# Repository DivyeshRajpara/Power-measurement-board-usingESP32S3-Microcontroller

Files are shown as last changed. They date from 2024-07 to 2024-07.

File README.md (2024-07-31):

# Power-measurement-board-usingESP32S3-Microcontroller
This project involves the development of a power-measurement board designed using KiCad and programmed with the ESP32-S3 microcontroller. The board measures electrical power and transmits the data via BLE to a mobile device. The project includes KiCad design files, ESP32-S3 firmware, and a mobile app interface for real-time data monitoring.
components
Hardware: KiCad design files for the power measurement board.
Firmware: ESP32-S3 code for data acquisition and BLE communication.
Devices: Interface for displaying real-time power data on a mobile device.
features
Power Measurement: Accurate measurement of voltage, current, and power.
Bluetooth Low Energy: Wireless data transmission to mobile devices.
ESP32-S3 Microcontroller: High-performance MCU with integrated Wi-Fi and BLE.
KiCad Design: Open-source PCB design with comprehensive schematics and layout files.
3D Top View
3D Bottom View

FootPrint AKL073
FootPrint INA239
FootPrint RTM_Solder Nail
With Dimension
With Ground
Without Ground
Schematic INA239

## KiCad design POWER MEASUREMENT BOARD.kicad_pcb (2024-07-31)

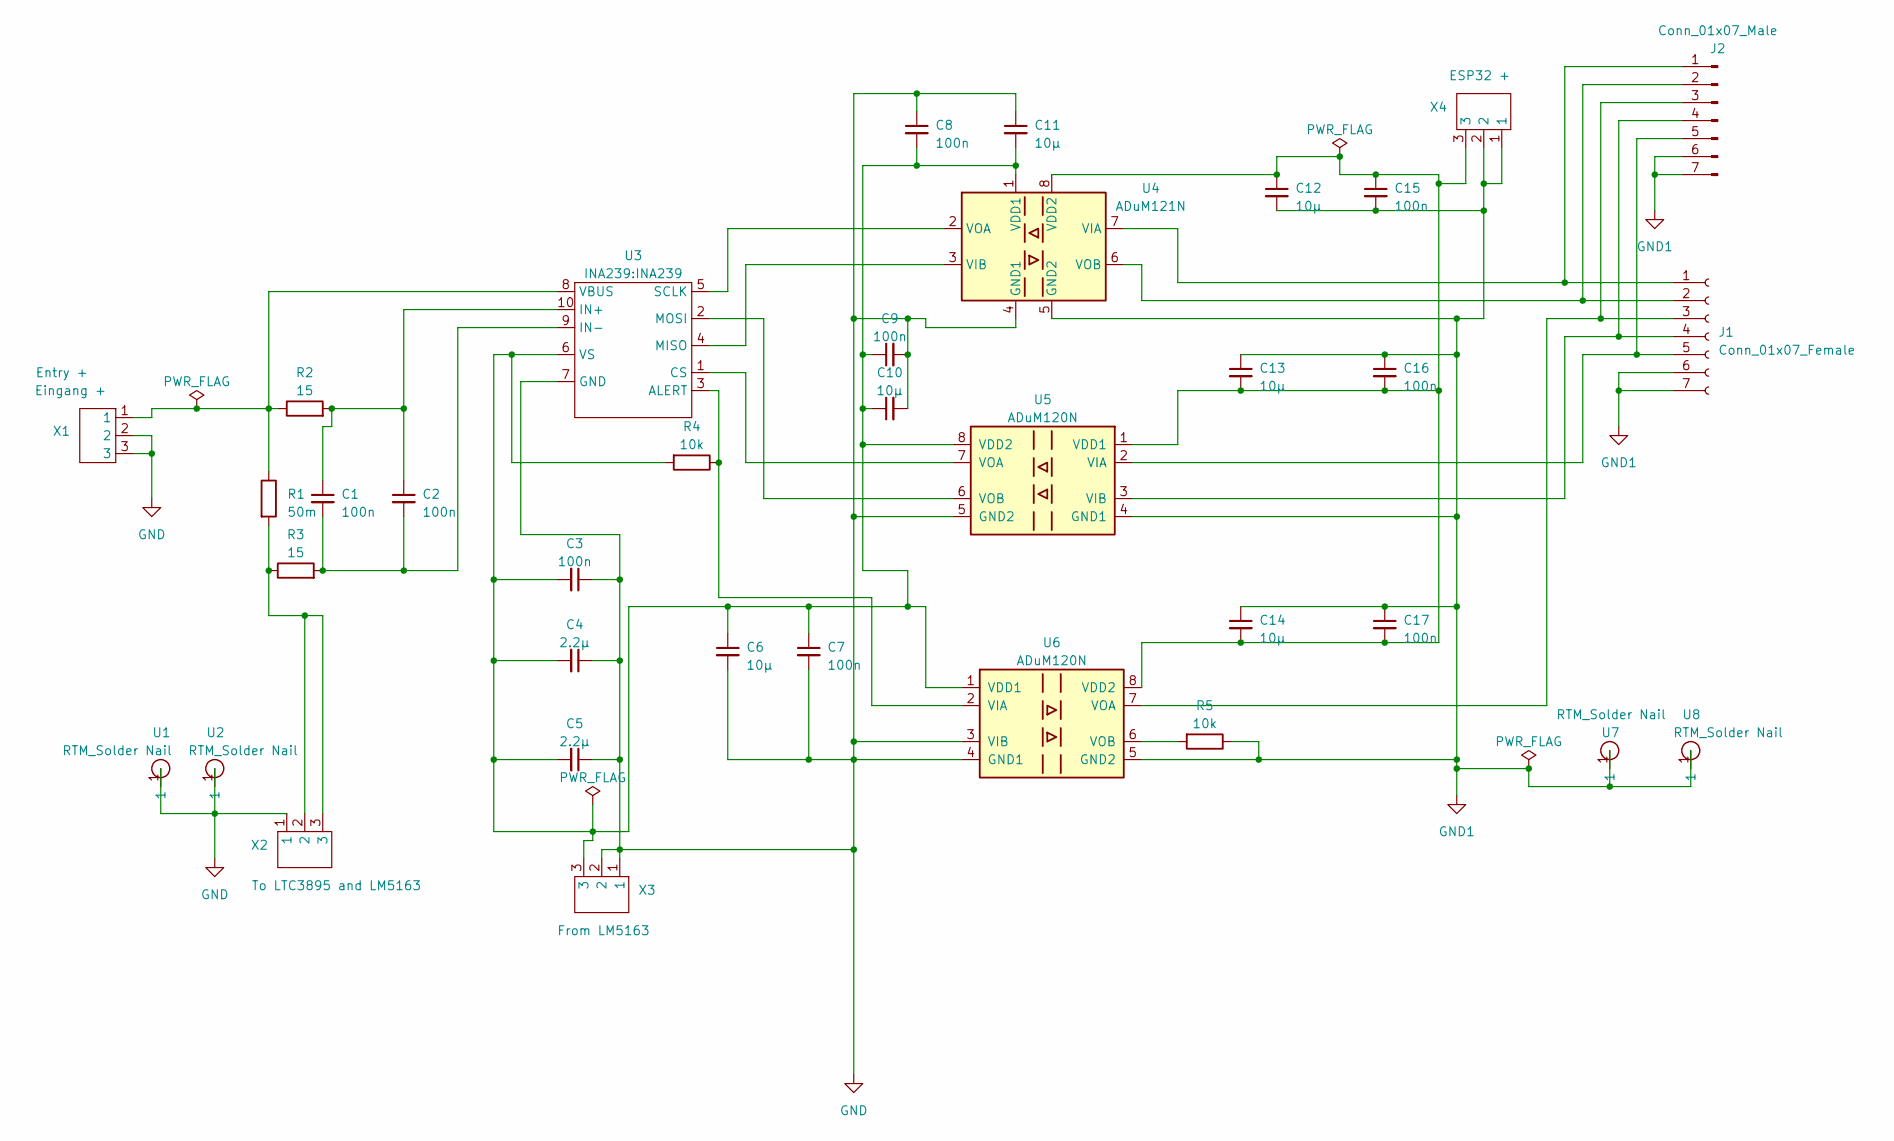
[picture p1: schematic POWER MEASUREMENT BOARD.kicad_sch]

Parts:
C1, C2, C15, C16, C17: 100n; C_0402_1005Metric_Pad0.74x0.62mm_HandSolder
C3, C7, C8, C9: 100n; C_0805_2012Metric_Pad1.18x1.45mm_HandSolder
C4, C5: 2.2μ; C_1206_3216Metric_Pad1.33x1.80mm_HandSolder
C6, C10, C11, C12, C13, C14: 10μ; C_1206_3216Metric_Pad1.33x1.80mm_HandSolder
J1: Conn_01x07_Female; PinSocket_1x07_P2.54mm_Vertical
J2: Conn_01x07_Male; PinHeader_1x07_P2.54mm_Vertical
R1: 50m; R_2010_5025Metric_Pad1.40x2.65mm_HandSolder
R2, R3: 15; R_0402_1005Metric_Pad0.72x0.64mm_HandSolder
R4, R5: 10k; R_0402_1005Metric_Pad0.72x0.64mm_HandSolder
U1, U2, U7, U8: RTM_Solder Nail
U3: INA239
U4: ADuM121N; SOIC-8_3.9x4.9mm_P1.27mm
U5, U6: ADuM120N; SOIC-8_3.9x4.9mm_P1.27mm
X1: Eingang +
X2: To LTC3895 and LM5163
X3: From LM5163
X4: ESP32 +

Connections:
GND: C3.1, C4.1, C5.1, C6.2, C7.2, C8.1, C9.2, C10.2, C11.1, U1.1, U2.1, U3.7 (GND), U4.4 (GND1), U5.5 (GND2), U6.3 (VIB), U6.4 (GND1), X1.2, X1.3, X2.1, X3.1, X3.2
GND1: C12.2, C13.1, C14.1, C15.2, C16.1, C17.1, J1.6, J1.7, J2.6, J2.7, R5.1, U4.5 (GND2), U5.4 (GND1), U6.5 (GND2), U7.1, U8.1, X4.1, X4.2
unnamed: J1.1, J2.1, U4.7 (VIA)
unnamed: J1.2, J2.2, U4.6 (VOB)
unnamed: J1.3, J2.3, U6.7 (VOA)
unnamed: J1.4, J2.4, U5.3 (VIB)
unnamed: J1.5, J2.5, U5.2 (VIA)
unnamed: R1.2, R3.1, X2.2, X2.3
unnamed: R4.1, U3.3 (ALERT), U6.2 (VIA)
unnamed: U3.1 (CS), U5.7 (VOA)
unnamed: C1.1, C2.1, R2.2, U3.10 (IN+)
unnamed: C1.2, C2.2, R3.2, U3.9 (IN-)
unnamed: U3.4 (MISO), U4.3 (VIB)
unnamed: U3.2 (MOSI), U5.6 (VOB)
unnamed: U3.5 (SCLK), U4.2 (VOA)
unnamed: R1.1, R2.1, U3.8 (VBUS), X1.1
unnamed: C3.2, C4.2, C5.2, C6.1, C7.1, C8.2, C9.1, C10.1, C11.2, R4.2, U3.6 (VS), U4.1 (VDD1), U5.8 (VDD2), U6.1 (VDD1), X3.3
unnamed: C12.1, C13.2, C14.2, C15.1, C16.2, C17.2, U4.8 (VDD2), U5.1 (VDD1), U6.8 (VDD2), X4.3
unnamed: R5.2, U6.6 (VOB)

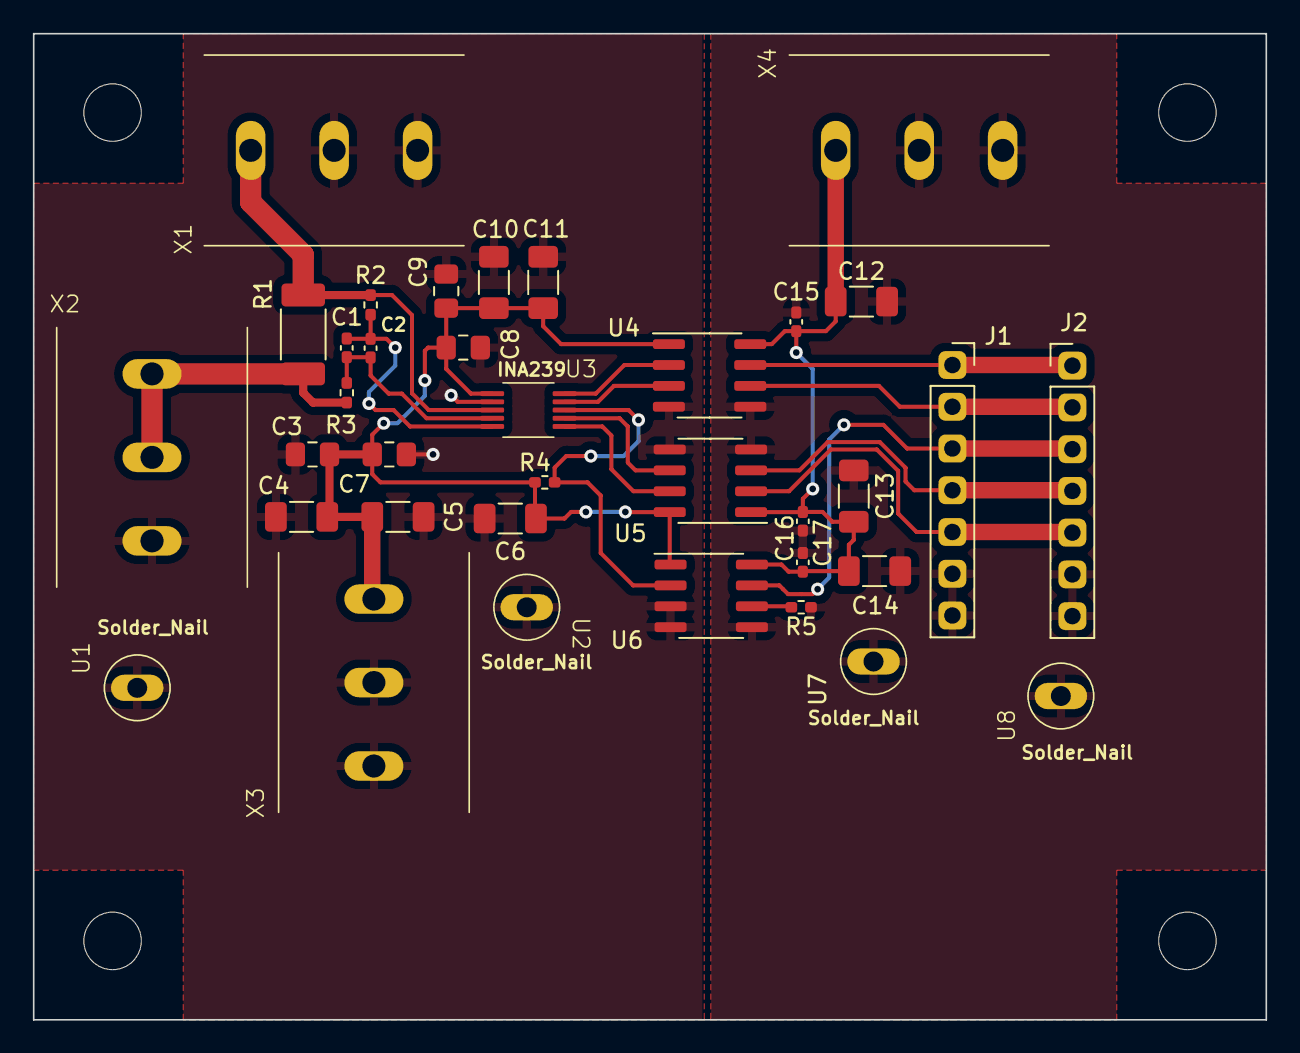
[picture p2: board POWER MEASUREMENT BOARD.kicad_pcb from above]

Board: 2 copper layers, 75.0 x 60.0 mm, 36 parts (0 on the bottom side), 19 nets.

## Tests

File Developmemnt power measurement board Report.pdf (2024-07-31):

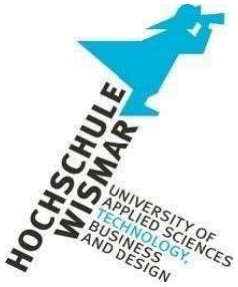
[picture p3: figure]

Hochschule Wismar University of
Applied Science Technology, Business and Design Faculty of Engineering Department of Electrical Engineering and Computer Science

## PROJECT SEMINAR

## :: Topic ::

## Development of a power-measurement board in KiCad and programming ESP32-S3 microcontroller with Bluetooth Low Energy for data transmission to a mobile device

### Mr.Divyesh Rajpara ( Matriculation Number : 419367)

Guided By

Prof. Dr.-Ing. Jens Kraitl
M. Eng. Andreas Hein

Project Seminar

## CONTENT

## 1. INTRODUCTION

In Project Seminar subject, student get opportunity to work on PCB designing KiCad designing software and also work on ESP32-S3 microcontroller. This year, main goal of this subject is to make design of Power-Measurement board in KiCad, which measure the voltage and current that generated from Photovoltaic panel. Measured device send measured current and voltage data to ESP32-S3 microcontroller board through SPI communication. Microcontroller share the data to mobile phone via Bluetooth connection. So that one can monitor generated updated data of current and voltage. The below figure represent basic block diagram of whole system.

Figure 1:- Block Diagram of System

### 1. INA 239:-

## 2. LIST OF COMPONENT

❖ The INA239 is an ultra-precise digital power monitor with a 16-bit delta-sigma ADC specifically designed for current-sensing applications. It measures shunt voltage, bus voltage and internal temperature while calculating current, power necessary for accurate decision making in precisely controlled systems. The main function of this device is to measure precise current and voltage, and it converts analog input to digital output [5].

### 2. ADuM120N and ADuM121N:-

❖ The ADuM120N and ADuM121N1 are dual-channel digital isolators. Combining high speed, complementary metal-oxide semiconductor (CMOS) and monolithic air core transformer technology, these isolation components provide outstanding performance characteristics superior to alternatives such as optocoupler devices and other integrated couplers. The maximum propagation delay is 13 ns with a pulse width distortion of less than 3 ns at 5 V operation. Channel matching is tight at 3.0 ns maximum. This device provides electrical isolation between various board parts, preventing voltage spikes, transients, or other disturbances from spreading over the isolation barrier. Digital isolator is able to maintain signal integrity by creating galvanic isolation between the measurement circuit and other component of system. Digital isolators offer interfaces between several voltage domains or communication methods. They may convert and isolate signals between various logic levels, assuring compatibility between the power measuring board and microcontrollers used in the system [6][7].
❖ The ADuM120N is a dual-channel digital isolator. It typically provides two distinct isolation channels, allowing for the isolation of two separate signals or data pathways.
❖ The ADuM121N is a quad-channel digital isolator. Up to four different signals or data pathways can be isolated using its four independent isolation channels.

### 3. ESP32-S3:-

❖ ESP32-S3 is a low-power MCU-based system on a chip (SoC) with integrated 2.4 GHz Wi-Fi and Bluetooth Low Energy (Bluetooth LE). It consists of high-performance dual-core microprocessor (Xtensa 32-bit LX7), a low power coprocessor, a Wi-Fi baseband, a Bluetooth LE baseband, RF module, and numerous peripherals. It has 45 programmable GPIOs. ESP32-S3 supports larger, high-speed octal SPI flash, and PSRAM with configurable data and instruction cache [8].

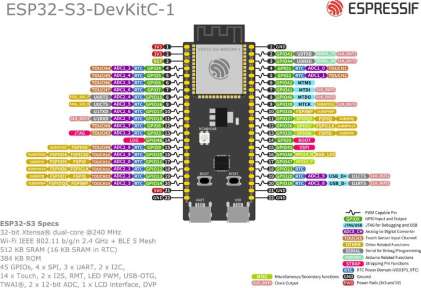
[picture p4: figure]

Figure 2:- Pin layout of ESP32-S3

1. Brief Introduction of kiCad Software.

## 3. KiCad

- KiCad is a free and open-source electronics design automation (EDA) suite. It features schematic capture, integrated circuit simulation, printed circuit board (PCB) layout, 3D rendering, and plotting/data export to numerous formats. KiCad also includes a high-quality component library featuring thousands of symbols, footprints, and 3D models [1][2].
- One can easily draw a circuit diagram in order to make Board layout in KiCad from pen paper based circuit, but person must know basic information and follow several rules for designing circuit such as,
a. Component Selection:- Selecting parts that are simple to find, satisfy your design specifications, and have corresponding footprints in KiCad's component libraries. Make sure the components you choose are appropriate for your project and are simple to get for manufacture. To match components that are not in the library, you may need to build unique footprints in KiCad.
b. Component Placement:- Place components on the PCB layout systematically to improve various kinds of factors like signal integrity, heat management, and manufacturing simplicity. Look of things like route simplicity, soldering accessibility, and component orientation. Component placement should be well-planned to minimize signal interference, ensure effective heat dissipation, and make assembly and testing easier.
c. Design Rules:- Create and set up KiCad design rules that are unique to your project. These regulations specify criteria like clearances, minimum trace widths, and other limitations on manufacture. These design guidelines must be followed in order to avoid problems during PCB production and assembly. You may make sure that your PCB layout complies with industry standards and manufacturing capabilities by defining appropriate design guidelines.
- Basic Terminology of KiCad:-
I. Schematic Editor:- A schematic designed with KiCad is more than a simple graphic representation of an electronic device [1]. A schematic mainly consists of symbols, wires, labels, junctions, buses and power symbols. When designing schematic a person must follow grid because wires connect with other wires or pins only if their ends coincide exactly. If a person not follow grid rule, then their schematic design have improper connection between wires and component. Therefore it is very important to keep symbol pins and wires aligned to the grid. The default grid size is 50 mil or 1.27 millimeters in KiCad. Symbols are added to the schematic from symbol libraries, after that all symbols connected with each other through wires and symbols also connected to necessary power symbols such as Ground and Power flag. After the schematic is made, the Electrical Rules Check (ERC) tool checks for certain errors in your schematic, such as unconnected pins, unconnected hierarchical symbols, shorted outputs or other illegal connections, etc. After rectifying errors a one is able to set of connections and footprints is imported into the PCB editor for designing a board [3].

❖ Explanation of Schematic design:- The following design is schematic design of Power measurement board. This design contains various components such as INA239, ADuM120N, ADuM121N, Male and Female connectors, Solder nail, 3-Pole screw connection terminals, different value Resistors and Capacitors. Photo-Voltaic panels, ESP32-S3 microcontroller, Synchronous buck converter and Synchronous step-down controller are externally connected to the Power measurement board through connection terminals. Generated voltage and current passed to the INA239 through R-C network. INA239 is generally used to sense voltage and current. Here, R1 resistor is parallel connected to 2 R-C circuit. This R-C circuit act as low-pass filter, which attenuating high frequency.

Here, Calculation of Shunt resistor,

Rshunt = Vmax/Imax

### Vmax = ± 163.4 mv (from the datasheet) Imax= Ioc = 3.4 A (from the datasheet)

### Rshunt = 163.4mV / (3.4 A)

### Rshunt ~= 0.4805Ω

At input side of INA239, voltage and current measured. Internally, these measured analog value data converted to digital data. INA239 is communicated with microcontroller through SPI protocol. In INA239, the objective of connecting a resistor between the INA239's power supply pin (Pin 6) and alert pin (Pin 3) is to monitor the power supply's status and provide an alert signal. Commonly known as a pull-up resistor, this resistor. Pull-up resistors are used to ensure that the alert pin (Pin 3) stays at a known voltage level (often the power supply voltage) even when the alert output is not actively driving it down. Pull-up resistors are connected between the power supply pin (Pin 6) and the alert pin (Pin 3). The alert pin is kept from floating, which could result in false readings or undefinable states, thanks to this configuration, which also helps to maintain a stable reference voltage. The INA239 actively pulls the alert pin when an alert circumstance arises.

❖ INA239 serially sent data to microcontroller through digital isolators. Voltage measurement channels are frequently found on power measuring boards because of different voltage measurement channel, these different channels generate interference in nearby channels which lead unwanted interferences in power measurement board. To avoid unwanted interference, electrical isolation is required in power measurement board. So that, digital isolator used in power measurement circuit. Because of SPI communication between microcontroller and current sensing device 2 ADuM120N and 1 ADuM121N digital isolator used. ADuM120N and ADuM121N isolator isolate 2 parts of power detection board, but these isolators transmit data between INA239 and ESP32-S3 controller. These 2 digital isolator used Magnetic Coupling technique. Signal transmission between the input and output sides is accomplished by means of a transformer-like device. Signals are transferred through the isolation barrier using magnetic fields.

❖ Output signal is transferred to the ESP32-S3 through screw connection terminals and J1socket and J2 pin from digital isolators. Here, Two capacitors are placed next to the isolator, connected in parallel, and have significant value discrepancies. The capacitor acts as a reservoir, absorbing extra charges when the voltage goes above its rated amount. The capacitor releases the collected charges when the voltage drops in order to keep a steady supply. Low-frequency voltage variations are handled by a 10 uF capacitor, whereas high-frequency voltage changes are handled by a 100 nF capacitor. On the output side of the isolator, a pull-up resistor is frequently used in order to establish a trustworthy digital connection between the two sides. By ensuring that the output signal is pulled to a specific voltage level while it is in the high state or not being actively pushed, this resistor helps. When the output signal is in the high state or not being actively pushed, this resistor helps to ensure that it is pulled to a specific voltage level. When the signal is not being driven actively, the pull-up resistor aids in maintaining a constant voltage level on the output side. It ensures a known and dependable signal level by preventing output from drifting or being impacted by noise.

❖ In the design of a measurement board, two supply voltages and two ground polygons are commonly utilized. There are two separate power supply used to protect analog and digital circuits from noise and interference. To ensure precision in measurements free from any digital noise or voltage changes, analog components require a stable and dependable power source. For digital circuits, also steady power source required in order to operate digital components. Because of 2 different circuits, 2 different voltage sources required to operate both circuit in desire way in.

❖ Here, 2 different polygons also used to avoid crosstalk and interference between analog and digital components can be prevented by designing separate ground planes for each kind of component. It aids in preventing the development of ground loops, which can corrupt signals and produce obtrusive noise.

❖ Operating range of power supply of this board is 2.7V to 5.5V. With help of this Power Measurement Board one can measure -0.3 to 85V input voltage and up to 10A current

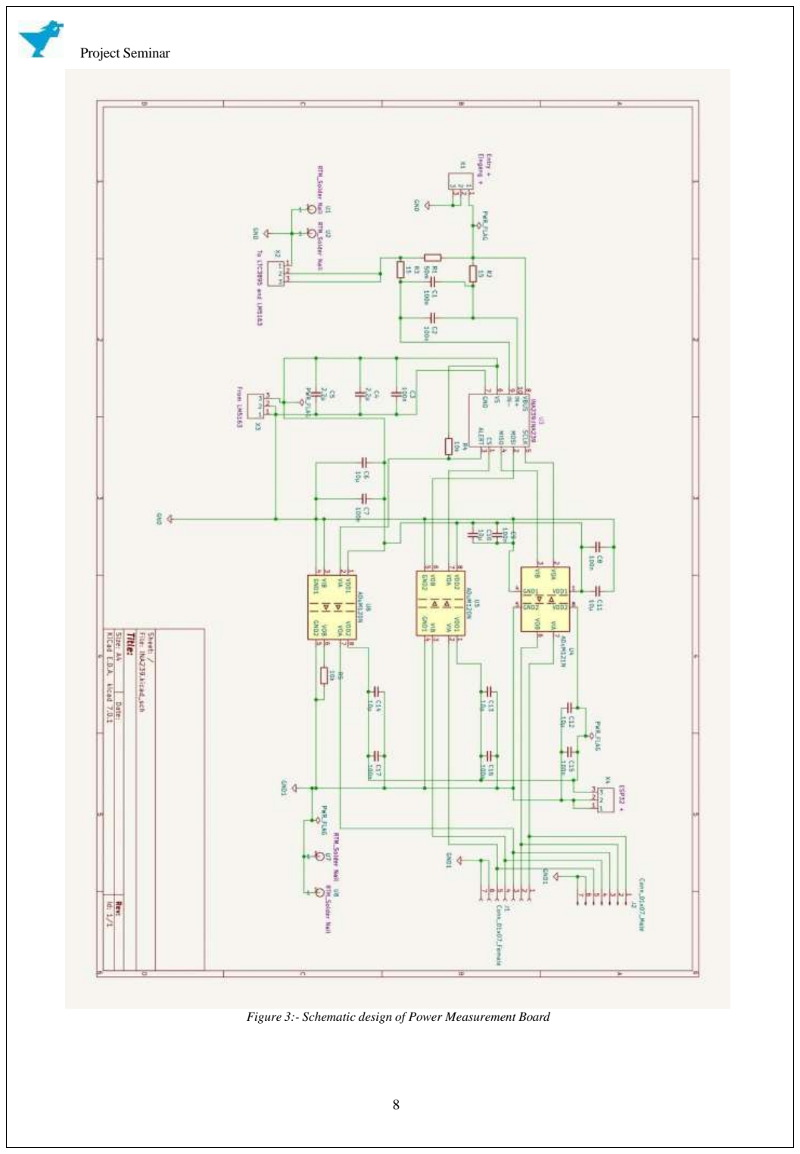
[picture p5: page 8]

Figure 3:- Schematic design of Power Measurement Board

II. Symbol Editor :- One can create own symbol library, create a new symbol library and also edit existing symbols for their specific Project [1]. A symbol represent appearance of electrical component. In the symbol editor, there are various tools as one can place a pin according to their requirement of symbols, also assign electrical type, number, and pin type to pin and make the desired shape of the symbol. With the help these tools one can manage to design their symbols for their project. Here, several examples of created symbols in symbol editor.

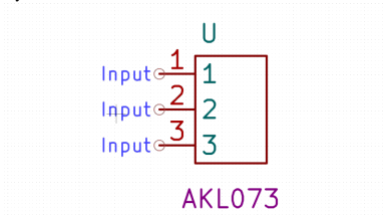
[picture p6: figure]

Figure 4:- Symbol design of AKL073

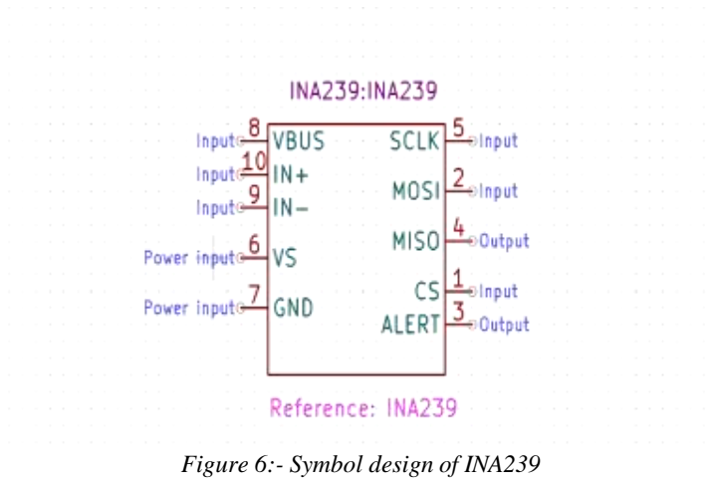
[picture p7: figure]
Figure 6:- Symbol design of INA239
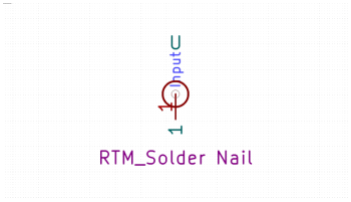
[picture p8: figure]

Figure 5:- Symbol design of RTM (Solder Nail)

III. | Footprint Editor:- With help of this editor anyone is able to create a new footprint and edit existing footprint. Footprints often represent physical electrical components [1]. Footprint editor have some different tools. Using Footprint template tool, one has to choose suitable template for footprint based on your component’s package type and one can manage to modify component’s physical dimensions and pin arrangement as per component’ datasheet. After creating footprint, person has to add Silkscreen markings on footprint to help in component placement and identification, then add Courtyard boarder which represents the boundary area around the component. After successfully creating footprint, one have to save to library and assign footprint library to specific name of symbol in symbol editor. Here the example of 2 different type of footprint such as SMD and Through-Hole.
| ❖ SMD:- In this type of footprint, one can be soldered component directly onto the surface of the PCB.

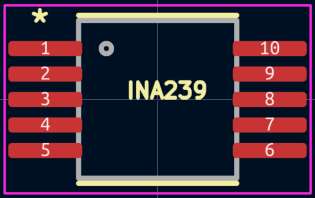
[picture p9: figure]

Figure 7:- Footprint design of INA239

- The rectangle uses the F.courtyard layer, and same the square uses the F.fab layer. Two lines are made up of the F.silkscreen layers, which is 3.5mm parallel to each other. Pads have round rectangle shape of 1.45 mm and 0.3mm with corner radius 0.075mm and 25% corner size.

❖ Through-Hole:- In this type of footprint, one have to pass component pins or leads through-hole and can be soldered on the back side of the PCB.

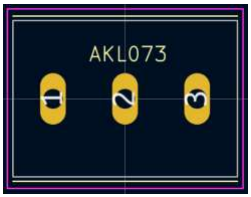
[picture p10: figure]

Figure 8:- Footprint design of AKL

- The rectangle uses the F.courtyard layer and smaller rectangle uses the F.fab layer. Two lines are made up of the F.silkscreen layers, which is 10.26mm parallel to each other. 3 Pads have oval rectangle shape of 1.8 mm and 3.4mm with diameter of 1.4mm.

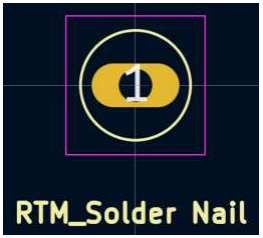
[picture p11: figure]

Figure 9:- Footprint design of RTM.

- The rectangle uses the F.courtyard layer. Circle with 2mm radius uses F.silkscreen layers with 0.1mm line width. Pads have oval rectangle shape of 1.6 mm and 3.2mm with diameter 1.21mm.

IV. PCB Editor:- With the help of this editor, anyone can create a new footprint and edit an existing footprint. Footprints often represent physical electrical components [4]. Footprint editors have some different tools. Using the Footprint template tool, one has to choose a suitable template for footprint based on your components:- In this editor, circuit designers create a Board layout or can modify the Board layout. If one has already created a schematic design of the circuit, then one can easily create a board layout from the schematic design. A person needs to import the netlist file into the PCB editor from Schematic. Because the netlist file contains information about the connection between components, which is important for Board layout. After importing the file, the designer should define the shape of the PCB by using a drawing tool. Then, one can place the component on the PCB layout. For component placement, designers have to consider some factors such as signal integrity, thermal management minimizing trace length, etc. In the next step, routing is started to connect components. In the routing task, the user should satisfy various rules, The posture of the track should not be 90 degrees, Width of the track depends on the connection between components. Track width is more in high power- consuming components compared to less power-consuming components. Some components can’t connect on the top layer, because of more connection. But with the help of Vias, one can connect those components through different layers. After routing, one can create polygons on the PCB layout that will be filled with copper for power and ground connection. Polygons is providing a low-impedance path for power distribution and ground reference plane. Later, the designer should run Design Rule Check. DRC checks the connection between components, trace width, and other electrical rules. After successfully creating a Board layout, one can view their board in 3D view using the 3D viewer.

- Many calculations are made during the board design phase of a project to ensure the functionality,
| reliability, and legality of the design such as,
| ❖ Trace Width and Current Capacity:- To avoid excessive resistance, voltage loss, and overheating, determine the appropriate trace width based on the maximum current.
| ❖ Decoupling Capacitor selection:- Determine the necessary capacitance for decoupling capacitors based on the desired voltage ripple and current demand.
| ❖ Thermal Analysis:- Using calculations for power dissipation, thermal resistance, and junction temperature, evaluate component temperature growth.

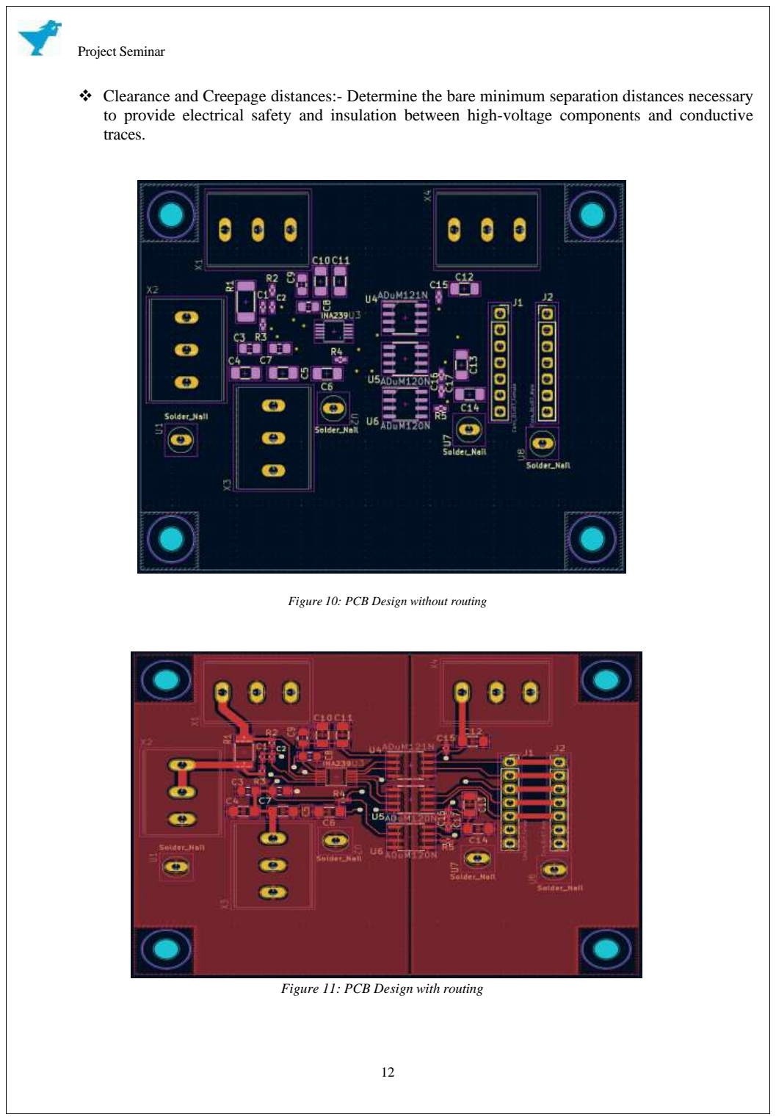
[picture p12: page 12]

❖ Clearance and Creepage distances:- Determine the bare minimum separation distances necessary to provide electrical safety and insulation between high-voltage components and conductive traces.

Figure 10: PCB Design without routing

Figure 11: PCB Design with routing


Figure 12:- Bottom layer design of PCB with B.cu

Figure 13:- PCB board layout Power Measurement Board


Figure 14:- Top view of 3D design of PCB

Figure 15:- Bottom View of 3D design of PCB

## 4. SERIAL PERIPHERAL INTERFACE

SPI is a synchronous serial communication interface used in electronic systems to connect peripheral devices, microcontrollers, and microprocessors. It enables master-slave architecture between devices, allowing data interchange. There are mainly three types of SPI of configurations are:

❖ Single slave configuration.
❖ Multi slave configuration.
❖ Daisy chain configuration.
1. Single slave configuration:- In this case, the master device is connected to a single slave. The master device manages communication with the slave device through the SPI bus. This is how SPI is set up in it is most basic and standard form.
2. Multi slave configuration:- In this system, a single master device connects with a number of slave devices. Each slave device has a distinct slave select (SS) line, which the master controls. The master identifies a certain slave by asserting the associated slave select line, and the selected slave and master can then converse.
3. Daisy chain configuration:- The MOSI line of the master (Master Output Slave Input) is connected to the MOSI input of the first slave. The MOSI output of the first slave is connected to the MOSI input of the second slave, and so on. The MISO (Master Input Slave Output) line is wired in the other direction and is similar to this. The master controls communication with each slave by selectively allowing or preventing data flow in the daisy chain.
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
